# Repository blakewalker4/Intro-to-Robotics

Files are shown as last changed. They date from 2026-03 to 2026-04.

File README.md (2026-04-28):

# Robo Car Companion

A voice-controlled robot car built for Intro to Robotics, Spring 2026. You talk to it, it listens, and it does what you say — including driving toward you when you tell it to "come here."

## How It Works (Big Picture)

There are two ESP32 boards. One sits on the mic array and handles all the listening and voice recognition. When it hears a command, it sends it over Bluetooth to the second ESP32 on the car, which drives the motors accordingly.

---

## Files

### `robo_car_companion.ino`
This runs on the robot car itself. It connects to the mic array board over Bluetooth and waits for commands to come in. When it gets one, it moves:

- **Go Forward / Go Backward** — drives straight, using the onboard gyroscope to self-correct and not drift
- **Turn Left / Turn Right / Turn Around** — rotates to a precise angle using the gyroscope
- **Spin** — just spins in place until told to stop
- **Dance** — does a little routine (forward, back, spin both ways)
- **Come Here** — rotates to face whoever spoke, then drives toward them
- **Stop** — stops whatever it's doing

### `mic_array_BLE_and_inferencing.ino`
This runs on a second ESP32-S3 that's connected to an XMOS XVF3800 microphone array. It does the heavy lifting:

- Continuously listens to audio from the mic array
- Runs a machine learning model (trained with Edge Impulse) to recognize voice commands in real time
- Reads the direction the sound came from (so "Come Here" knows which way to turn)
- Sends recognized commands over Bluetooth to the car

It's set up to only fire a command once it's confident — it requires the model to agree with itself across multiple audio windows before sending anything.

### `mic_array_write_sound_to_serial.ino`
A helper sketch used during development. Instead of doing any inference, it just streams raw audio from the mic array to your computer over USB. This was used to collect training data for the voice model.

### `I2SAudioCollect.py`
A Python script that runs on your computer alongside `mic_array_write_sound_to_serial.ino`. It reads the audio coming in over serial and saves it as `.wav` files, organized into folders by label (e.g., "Dance", "Stop"). Used to build the dataset that the voice model was trained on.

### `micholder.STL`
A 3D-printable mount for the microphone array. Print it and attach it to the car.

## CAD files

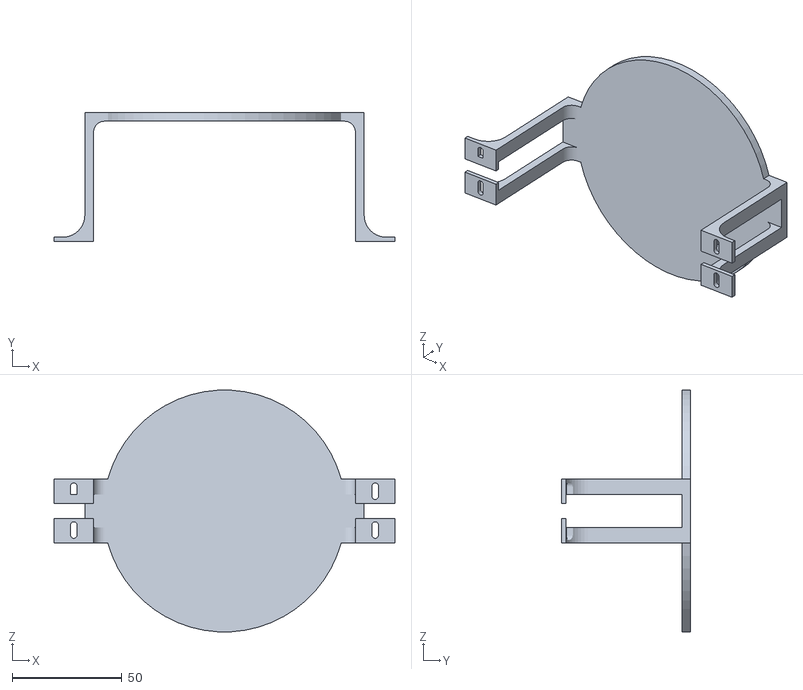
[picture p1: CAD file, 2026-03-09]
micholder.STL
155.0 x 58.7 x 109.8

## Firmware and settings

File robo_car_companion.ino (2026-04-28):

#include <basicMPU6050.h>
#include "BLEDevice.h"
#include "string.h"

// state declarations
enum MyState {
  IDLE,
  DANCE,
  SPIN,
  TURNLEFT,
  TURNRIGHT,
  TURNAROUND,
  COMEHERE,
  GOBACKWARD,
  GOFORWARD
};

MyState state = IDLE;

// Function definitions
void stop(int time_dur = 100);

// Motor and PWM stuff
/*
 * IN1   IN2   | Motor Behavior
 * ----------  | 
 * HIGH  LOW   | Clockwise (forward for right motor)
 * LOW   HIGH  | Counter-Clockwise (forward for left motor)
 * HIGH  HIGH  | Brake (fast stop)
 * LOW   LOW   | Coast (slow stop)
 */
// Note: Motor speed is a 8 bit value between 0 and 255
//       but anything below about 160 will not make the motors move


// left motors
#define ENA 32 // PWM pin for left motor speed
#define IN1 33 // Digital pin - direction
#define IN2 25 // Digital pin - direction

// right motors
#define ENB 14 // PWM pin for right motor speed
#define IN3 26 // Digital pin - direction
#define IN4 27 // Digital pin - direction

// PWM settings
#define PWM_FREQ 5000      // 5 kHz is good for DC motors
#define PWM_RESOLUTION 8   // 8-bit resolution (0-255)

// Speed settings
int max_adjustment = 50;  // Maximum speed change between motors

// IMU stuff
basicMPU6050<> imu;

// Bluetooth stuff
// The remote service we wish to connect to.
static BLEUUID serviceUUID("4fafc201-1fb5-459e-8fcc-c5c9c331914b");
// The characteristic of the remote service we are interested in.
static BLEUUID charUUID("beb5483e-36e1-4688-b7f5-ea07361b26a8");

static boolean doConnect = false;
static boolean connected = false;
static boolean doScan = false;
static BLERemoteCharacteristic* pRemoteCharacteristic;
static BLEAdvertisedDevice* myDevice;

static void notifyCallback(
  BLERemoteCharacteristic* pBLERemoteCharacteristic,
  uint8_t* pData,
  size_t length,
  bool isNotify) {
    Serial.print("data: ");

    // Copy into a null-terminated buffer before printing
    char buf[length + 1];
    memcpy(buf, pData, length);
    buf[length] = '\0';
    char come_here_buf[4];

    if(state == IDLE){
      if(strcmp(buf, "Dance")==0){
        state = DANCE;
      }
      else if(strcmp(buf, "Spin")==0){
        state = SPIN;
      }
      else if(strcmp(buf, "TurnLeft")==0){
        state = TURNLEFT;
      }
      else if(strcmp(buf, "TurnRight")==0){
        state = TURNRIGHT;
      }
      else if(strcmp(buf, "TurnAround")==0){
        state = TURNAROUND;
      }
      else if(strcmp(buf, "GoForward")==0){
        state = GOFORWARD;
      }
      else if(strcmp(buf, "GoBackward")==0){
        state = GOBACKWARD;
      }
      else if (strcmp(buf, "Stop") == 0){
          ;
        }
      // last class it could be is ComeHere
      // ComeHere is returned as "ComeHere:<doa>"
      else{
        state = COMEHERE;
        uint8_t idx = 0;
        while(buf[idx] != ':'){
          idx++;
        }
        idx++;
        uint8_t idx2 = 0;
        while(buf[idx] != '\0'){
          come_here_buf[idx2++] = buf[idx++];
        }
        come_here_buf[idx2] = '\0';
        
        uint16_t angle = atoi(come_here_buf);

        Serial.print("doa val: ");
        Serial.println(angle);

        delay(10);
        rotateToAngleIMU(angle, 200, true);
      }
    }
    else{
      if(strcmp(buf, "Stop")==0){
        stop();
      }
    }
}

class MyClientCallback : public BLEClientCallbacks {
  void onConnect(BLEClient* pclient) {
  }

  void onDisconnect(BLEClient* pclient) {
    connected = false;
    Serial.println("onDisconnect");
  }
};

bool connectToServer() {
  Serial.print("Forming a connection to ");
  Serial.println(myDevice->getAddress().toString().c_str());
  
  BLEClient*  pClient  = BLEDevice::createClient();
  Serial.println(" - Created client");

  pClient->setClientCallbacks(new MyClientCallback());

  // Connect to the remove BLE Server.
  pClient->connect(myDevice);  // if you pass BLEAdvertisedDevice instead of address, it will be recognized type of peer device address (public or private)
  Serial.println(" - Connected to server");

  // Obtain a reference to the service we are after in the remote BLE server.
  BLERemoteService* pRemoteService = pClient->getService(serviceUUID);
  if (pRemoteService == nullptr) {
    Serial.print("Failed to find our service UUID: ");
    Serial.println(serviceUUID.toString().c_str());
    pClient->disconnect();
    return false;
  }
  Serial.println(" - Found our service");

  // Obtain a reference to the characteristic in the service of the remote BLE server.
  pRemoteCharacteristic = pRemoteService->getCharacteristic(charUUID);
  if (pRemoteCharacteristic == nullptr) {
    Serial.print("Failed to find our characteristic UUID: ");
    Serial.println(charUUID.toString().c_str());
    pClient->disconnect();
    return false;
  }
  Serial.println(" - Found our characteristic");

  // Read the value of the characteristic.
  if(pRemoteCharacteristic->canRead()) {
    String value = pRemoteCharacteristic->readValue();
    Serial.print("The characteristic value was: ");
    Serial.println(value.c_str());
  }

  if(pRemoteCharacteristic->canNotify())
    pRemoteCharacteristic->registerForNotify(notifyCallback);

  connected = true;
  return true;
}

// Scan for BLE servers and find the first one that advertises the service we are looking for.
class MyAdvertisedDeviceCallbacks: public BLEAdvertisedDeviceCallbacks {
 // Called for each advertising BLE server.
  void onResult(BLEAdvertisedDevice advertisedDevice) {
    Serial.print("BLE Advertised Device found: ");
    Serial.println(advertisedDevice.toString().c_str());

    // We have found a device, let us now see if it contains the service we are looking for.
    if (advertisedDevice.haveServiceUUID() && advertisedDevice.isAdvertisingService(serviceUUID)) {

      BLEDevice::getScan()->stop();
      myDevice = new BLEAdvertisedDevice(advertisedDevice);
      doConnect = true;
      doScan = true;

    } // Found our server
  } // onResult
}; // MyAdvertisedDeviceCallbacks

float deg2rad(float degrees){
  return degrees*3.141592/180;
}

void turnCW(int speed, int time_dur){
  // set left motors to reverse
  digitalWrite(IN1, LOW);
  digitalWrite(IN2, HIGH);
  // set right motors to forward
  digitalWrite(IN3, HIGH);
  digitalWrite(IN4, LOW);
  unsigned long start_time = millis();
  unsigned long cur_time = millis();
  while(cur_time - start_time < time_dur){
    ledcWrite(ENA, speed);
    ledcWrite(ENB, speed);
    cur_time = millis();
  }
}

void turnCCW(int speed, int time_dur){
  // set left motors to forward
  digitalWrite(IN1, HIGH);
  digitalWrite(IN2, LOW);
  // set right motors to reverse
  digitalWrite(IN3, LOW);
  digitalWrite(IN4, HIGH);
  unsigned long start_time = millis();
  unsigned long cur_time = millis();
  while(cur_time - start_time < time_dur){
    ledcWrite(ENA, speed);
    ledcWrite(ENB, speed);
    cur_time = millis();
  }
}

void goForward(int speed){
  // set left motors to forward
  digitalWrite(IN1, HIGH);
  digitalWrite(IN2, LOW);
  // set right motors to forward
  digitalWrite(IN3, HIGH);
  digitalWrite(IN4, LOW);
  ledcWrite(ENA, speed);
  ledcWrite(ENB, speed);
}

void goBackward(int speed){
  // set left motors to reverse
  digitalWrite(IN1, LOW);
  digitalWrite(IN2, HIGH);
  // set right motors to reverse
  digitalWrite(IN3, LOW);
  digitalWrite(IN4, HIGH);
  ledcWrite(ENA, speed);
  ledcWrite(ENB, speed);
}

void stop(int time_dur){
  // set left motors to stop
  digitalWrite(IN1, HIGH);
  digitalWrite(IN2, HIGH);
  // set right motors to stop
  digitalWrite(IN3, HIGH);
  digitalWrite(IN4, HIGH);
  ledcWrite(ENA, 255);
  ledcWrite(ENB, 255);
  delay(time_dur);
  state = IDLE;
}

void spin(int speed){ // turn CW until another command comes in
  // set left motors to forward
  digitalWrite(IN1, HIGH);
  digitalWrite(IN2, LOW);
  // set right motors to reverse
  digitalWrite(IN3, LOW);
  digitalWrite(IN4, HIGH);
  ledcWrite(ENA, speed);
  ledcWrite(ENB, speed);
}

void dance(){
  goForward(200);
  delay(1000);
  goBackward(200);
  delay(1000);
  turnCW(230, 1000);
  turnCCW(230, 1000);
  stop();
}

void goStraightIMU(int base_speed){ // Unified function for goForward and goBackward
  // PID constants for drift correction
  float Kp_forward = 40;  // Proportional gain - adjust as neccessary
  float Ki_forward = 0.3; // Integral gain - adjust as neccessary
  float Kp_backward = 40;  // Proportional gain - adjust as neccessary
  float Ki_backward = 0.3; // Integral gain - adjust as neccessary
  float Kp;
  float Ki;
  float Kd = 0;  // Derivative gain - adjust as neccessary
  float previous_error = 0;
  float integral = 0;
  unsigned long last_time = micros();
  unsigned long start_time = micros();
  unsigned long now = micros();
  int left_speed;
  int right_speed;
  float correction;
  //unsigned long timeout = 7000; // 7 second timeout safety
  while(state == GOFORWARD || state == GOBACKWARD){
    // Calculate loop time for proper PID
    now = micros();
    float dt = (now - last_time) / 1000000.0;  // Convert to seconds
    last_time = now;
    
    // Get gyro Z-axis (turning rate)
    float turn_rate = imu.gz();  // degrees per second
    
    // We want turn rate to be 0 (going straight)
    float error = 0 - turn_rate;
    
    // PID calculations
    integral += error * dt;
    float derivative = (error - previous_error) / dt;
    
    // Calculate motor speeds
    if(state == GOFORWARD){
      Kp = Kp_forward;
      Ki = Ki_forward;

      // Calculate correction
      correction = Kp * error + Ki * integral + Kd * derivative;
      
      // Constrain correction
      correction = constrain(correction, -max_adjustment, max_adjustment);
      
      // Set motor speeds
      left_speed = base_speed - correction;   // If correction positive, left slower
      right_speed = base_speed + correction;  // If correction positive, right faster
      
      // Set motor directions
      // set left motors to forward
      digitalWrite(IN1, HIGH);
      digitalWrite(IN2, LOW);
      // set right motors to forward
      digitalWrite(IN3, HIGH);
      digitalWrite(IN4, LOW);
    }
    // NOTE: when going backward, the PID controller is doing very little 
    // to correct for the integral error, even if Ki_backward is very high, dont know why.
    // The controlled version is still slightly better though
    else if(state == GOBACKWARD){
      Kp = Kp_backward;
      Ki = Ki_backward;

      // Calculate correction
      correction = Kp * error + Ki * integral + Kd * derivative;
      
      // Constrain correction
      correction = constrain(correction, -max_adjustment, max_adjustment);
      
      // Set motor speeds
      left_speed = base_speed + correction;   // If correction positive, left slower
      right_speed = base_speed - correction;  // If correction positive, right faster
            
      // Set motor directions
      // set left motors to backward
      digitalWrite(IN1, LOW);
      digitalWrite(IN2, HIGH);
      // set right motors to backward
      digitalWrite(IN3, LOW);
      digitalWrite(IN4, HIGH);
    }
    else{
      // INVALID STATE
      break;
    }
    // Constrain speeds
    left_speed = constrain(left_speed, 0, 255);
    right_speed = constrain(right_speed, 0, 255);
    
    // Apply PWM speeds
    ledcWrite(ENA, left_speed);
    ledcWrite(ENB, right_speed);
    
    // Debug output
    /*
    Serial.print("Turn Rate: ");
    Serial.println(turn_rate);
    Serial.print(" deg/s, Correction: ");
    Serial.println(correction);
    Serial.print(" L: ");
    Serial.println(left_speed);
    Serial.print(" R: ");
    Serial.println(right_speed);
    Serial.print("Time elapsed: ");
    Serial.println(float((now-start_time)/1000000));
    Serial.println("");
    */
    
    previous_error = error;
    delay(10);  // 100Hz control loop
  }
  Serial.println("exiting loop");
  stop();
}

void rotateToAngleIMU(float target_angle_degrees, int base_speed, bool come_here_flag) {
  // PID constants for rotation (tune these)
  float Kp_rotate = 3;  // Proportional gain
  float Ki_rotate = 0.05;  // Integral gain  
  float Kd_rotate = 0;   // Derivative gain
  float current_angle = 0;
  float previous_error = 0;
  float integral = 0;
  unsigned long last_time = micros();
  unsigned long start_time = millis();

  bool clockwise;
  float target_rad;
  // For rotations > 180°, consider the shortest path
  if(target_angle_degrees <= 180) {
    // Turn clockwise for angles 0-180
    clockwise = true;
    target_rad = deg2rad(target_angle_degrees);
  } else {
    // Turn counter-clockwise for angles 181-360 (shorter)
    clockwise = false;
    target_rad = deg2rad(360 - target_angle_degrees);
  }
  
  // Rotate until reaching target angle
  while(state != IDLE && abs(current_angle) < target_rad) {
    unsigned long now = micros();
    float dt = (now - last_time) / 1000000.0;
    if(dt > 0.05) dt = 0.05;
    last_time = now;
    
    // Get current rotation rate
    float turn_rate = imu.gz();
    
    // Integrate to get angle
    current_angle += abs(turn_rate) * dt;
    
    // Calculate error (how much more to turn)
    float error = target_rad - abs(current_angle);
    
    // PID calculations
    integral += error * dt;
    
    float derivative = (error - previous_error) / dt;
    
    // Calculate motor speed based on error
    int speed = base_speed + Kp_rotate * error + Ki_rotate * integral + Kd_rotate * derivative;
    speed = constrain(speed, 170, 230);

    // Set motors for rotation
    if(clockwise) {
      // Clockwise: left forward, right backward
      digitalWrite(IN1, LOW); digitalWrite(IN2, HIGH);
      digitalWrite(IN3, HIGH); digitalWrite(IN4, LOW);

    }
    else {
      // Counter-clockwise: left backward, right forward  
      digitalWrite(IN1, HIGH); digitalWrite(IN2, LOW);
      digitalWrite(IN3, LOW); digitalWrite(IN4, HIGH);
    }
    
    // Apply speed
    ledcWrite(ENA, speed);
    ledcWrite(ENB, speed);
    
    delay(5);  // 200Hz update rate
  }
  if(!come_here_flag){
    // Stop motors
    stop();
  }
  
  
  Serial.print("Final rotation: ");
  Serial.println(current_angle);
}

void setup() {
  // Setup PWM for speed control
  ledcAttach(ENA, PWM_FREQ, PWM_RESOLUTION);
  ledcAttach(ENB, PWM_FREQ, PWM_RESOLUTION);

  // Setup direction pins as regular digital outputs
  pinMode(IN1, OUTPUT); 
  pinMode(IN2, OUTPUT); 
  pinMode(IN3, OUTPUT); 
  pinMode(IN4, OUTPUT); 

  // Setup MPU6050
  imu.setup();
  imu.setBias();  // Calibrate gyro when car is stationary
  
  Serial.begin(115200);
  // BLUETOOTH STUFF: COMMENTING OUT FOR TESTING
  Serial.println("Starting Arduino BLE Client application...");
  BLEDevice::init("");

  // Retrieve a Scanner and set the callback we want to use to be informed when we
  // have detected a new device.  Specify that we want active scanning and start the
  // scan to run for 5 seconds.
  BLEScan* pBLEScan = BLEDevice::getScan();
  pBLEScan->setAdvertisedDeviceCallbacks(new MyAdvertisedDeviceCallbacks());
  pBLEScan->setInterval(1349);
  pBLEScan->setWindow(449);
  pBLEScan->setActiveScan(true);
  pBLEScan->start(5, false);
  // set all motors to off by default
  stop();
}

void loop() {
  // If the flag "doConnect" is true then we have scanned for and found the desired
  // BLE Server with which we wish to connect.  Now we connect to it.  Once we are 
  // connected we set the connected flag to be true.
  if (doConnect == true) {
    if (connectToServer()) {
      Serial.println("We are now connected to the BLE Server.");
    } else {
      Serial.println("Failed to connect to server.");
    }
    doConnect = false;
  }

  // If we are connected to a peer BLE Server, update the characteristic each time we are reached
  // with the current time since boot.
  if (connected) {
    String newValue = "";
    
    // Set the characteristic's value to be the array of bytes that is actually a string.
    pRemoteCharacteristic->writeValue(newValue.c_str(), newValue.length());
  }else if(doScan){
    BLEDevice::getScan()->start(0);  // this is just example to start scan after disconnect
  }

  if(state == IDLE){
    ;
  }
  else if(state == DANCE){
    dance();
  }
  else if(state == SPIN){
    spin(210);
  }
  else if(state == TURNLEFT){
    rotateToAngleIMU(270, 200, false);
  }
  else if(state == TURNRIGHT){
    rotateToAngleIMU(90, 200, false);
  }
  else if(state == TURNAROUND){
    rotateToAngleIMU(180,200, false);
  }
  else if(state == GOFORWARD){
    goStraightIMU(190);
  }
  else if(state == GOBACKWARD){
    goStraightIMU(190);
  }
  else if(state == COMEHERE){
    //already did the turn in the notifyCallback function
    state = GOFORWARD;
    goStraightIMU(190);
  }
  delay(1000); // Delay a second between loops.
}

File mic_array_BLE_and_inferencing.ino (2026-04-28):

#define EIDSP_QUANTIZE_FILTERBANK   0
#include <rcmarkowitz-project-1_inferencing.h>
#include "driver/i2s.h"
#include "freertos/FreeRTOS.h"
#include "freertos/task.h"
#include "freertos/queue.h"
#include "freertos/semphr.h"
#include <BLEDevice.h>
#include <BLEServer.h>
#include <BLEUtils.h>
#include <BLE2902.h>
#include <Wire.h>
#include <string.h>

#define XMOS_ADDR 0x2C

#define GPO_SERVICER_RESID            20
#define GPO_SERVICER_RESID_LED_EFFECT 12
#define GPO_SERVICER_RESID_DOA        19
#define GPO_DOA_READ_NUM_BYTES        4

// === BLE CONFIG ===
BLEServer* pServer = NULL;
BLECharacteristic* pCharacteristic = NULL;
bool deviceConnected = false;
bool oldDeviceConnected = false;
uint32_t value = 0;

#define SERVICE_UUID        "4fafc201-1fb5-459e-8fcc-c5c9c331914b"
#define CHARACTERISTIC_UUID "beb5483e-36e1-4688-b7f5-ea07361b26a8"

void write_led_effect(uint8_t effect);

class MyServerCallbacks: public BLEServerCallbacks {
    void onConnect(BLEServer* pServer) {
      deviceConnected = true;
      write_led_effect(4);
    };
    void onDisconnect(BLEServer* pServer) {
      deviceConnected = false;
      write_led_effect(3);
    }
};

QueueHandle_t command_queue;

// ==== AUDIO CONFIG ====
#define I2S_PORT            I2S_NUM_0
#define I2S_WS              7
#define I2S_SD              43
#define I2S_SCK             8

#define SAMPLE_RATE         48000
#define I2S_SAMPLE_BITS     32
#define SAMPLE_BUFFER_SIZE  2048

// ==== SLIDING WINDOW CONFIG ====
#define SLICES_PER_WINDOW   3
#define SLICE_SIZE          (EI_CLASSIFIER_RAW_SAMPLE_COUNT / SLICES_PER_WINDOW)

// ==== CONSECUTIVE-AGREEMENT CONFIG ====
#define CONSECUTIVE_REQUIRED 2

// ==== BUFFERS ====
static int32_t  i2s_samples[SAMPLE_BUFFER_SIZE];
static int16_t  slice_buffer_a[SLICE_SIZE];
static int16_t  slice_buffer_b[SLICE_SIZE];
static int16_t *write_slice = slice_buffer_a;
static int16_t *read_slice  = slice_buffer_b;
static int16_t  rolling_buffer[EI_CLASSIFIER_RAW_SAMPLE_COUNT];

static volatile uint32_t slice_count = 0;
static volatile bool     slice_ready = false;

static bool record_status = true;
static bool debug_nn      = false;

// ==== DOA POLLING BUFFER ====
#define DOA_BUF_SIZE           64
#define DOA_BUCKET_DEGREES     5
#define DOA_WINDOW_MS          1500
#define VAD_MAJORITY_THRESHOLD 0.3f  // at least 30% of window samples must have VAD=1

typedef struct {
    uint16_t angle;
    uint8_t  vad;
    uint32_t timestamp_ms;
} doa_sample_t;

typedef struct {
    uint16_t angle;     // 0xFFFF if no valid angle
    bool     speech_detected;
} doa_result_t;

static doa_sample_t  doa_poll_buf[DOA_BUF_SIZE];
static uint8_t       doa_poll_head  = 0;
static uint8_t       doa_poll_count = 0;
static SemaphoreHandle_t doa_mutex;

// ==== FUNCTION DECLARATIONS ====
static void audio_inference_callback(uint32_t n_bytes);
static void capture_samples(void *arg);
static void ble_sender_task(void *arg);
static void doa_poll_task(void *arg);
static int  microphone_audio_signal_get_data(size_t offset, size_t length, float *out_ptr);
static int  i2s_init();
static void i2s_deinit();
static doa_result_t get_doa_result();

void setup() {
    Serial.begin(115200);
    delay(3000);
    Wire.begin();
    Serial.println("XVF3800 Keyword Spotting - Sliding Window");
    Serial.print("Deploy version: ");
    Serial.println(EI_CLASSIFIER_PROJECT_DEPLOY_VERSION);
    Serial.print("Slice size: ");
    Serial.println(SLICE_SIZE);
    Serial.print("Raw Sample Count: ");
    Serial.println(EI_CLASSIFIER_RAW_SAMPLE_COUNT);

    memset(rolling_buffer, 0, sizeof(rolling_buffer));

    if (i2s_init() != 0) {
        Serial.println("ERR: I2S init failed");
        while(1);
    }

    write_led_effect(3);

    doa_mutex = xSemaphoreCreateMutex();

    BLEDevice::init("ESP32-S3");
    pServer = BLEDevice::createServer();
    pServer->setCallbacks(new MyServerCallbacks());
    BLEService *pService = pServer->createService(SERVICE_UUID);
    pCharacteristic = pService->createCharacteristic(
                        CHARACTERISTIC_UUID,
                        BLECharacteristic::PROPERTY_READ   |
                        BLECharacteristic::PROPERTY_WRITE  |
                        BLECharacteristic::PROPERTY_NOTIFY |
                        BLECharacteristic::PROPERTY_INDICATE
                    );
    pCharacteristic->addDescriptor(new BLE2902());
    pService->start();
    BLEAdvertising *pAdvertising = BLEDevice::getAdvertising();
    pAdvertising->addServiceUUID(SERVICE_UUID);
    pAdvertising->setScanResponse(false);
    pAdvertising->setMinPreferred(0x0);
    BLEDevice::startAdvertising();
    Serial.println("Waiting a client connection to notify...");

    command_queue = xQueueCreate(5, sizeof(const char *));
    xTaskCreate(ble_sender_task, "BLESender", 4096, NULL, 1, NULL);
    xTaskCreate(capture_samples, "CaptureSamples", 4096, NULL, 1, NULL);
    xTaskCreate(doa_poll_task,   "DoAPoll",        2048, NULL, 1, NULL);
    Serial.println("Listening...");
}
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

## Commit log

2026-02-21 First arduino motor code
2026-02-22 Added basic commands and test functions
    also determined speed range for motor (about 170-255)
2026-03-01 Added MPU 6050 code
    untested. I know the reading of the MPU works but i still need to test the PID error correction and tune some variables.
    Most credit goes to Deepseek.
    I think we should figure out how to set up ESPNOW or some other kind of communication so we can get serial info from the robot while its running easier.
2026-03-09 mic array stand for chassis
    [micholder.STL]
2026-04-13 Added IMU PID control
    for rotation and backwards movement
2026-04-28 Fixed come here function
    [robo_car_companion.ino]
